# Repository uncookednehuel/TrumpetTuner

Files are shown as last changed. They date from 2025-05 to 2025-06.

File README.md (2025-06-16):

# TrumpetTuner
Resources of the capstone engineering project by Nehuel Armenanzas, Dylan Hong, and Logan Bruno

## Files
We currently have the final report PDF, the CAD models, the arduino source code, and some photos, all provided above. Let me know at coolnehuel@gmail.com if you have any questions or would like to know anything else about this project!

## Team
We are 3 seniors from Portsmouth High School, and we made this device prototype as our senior engineering capstone project. We all completed the Engineering CTE pathway, and are now graduated!

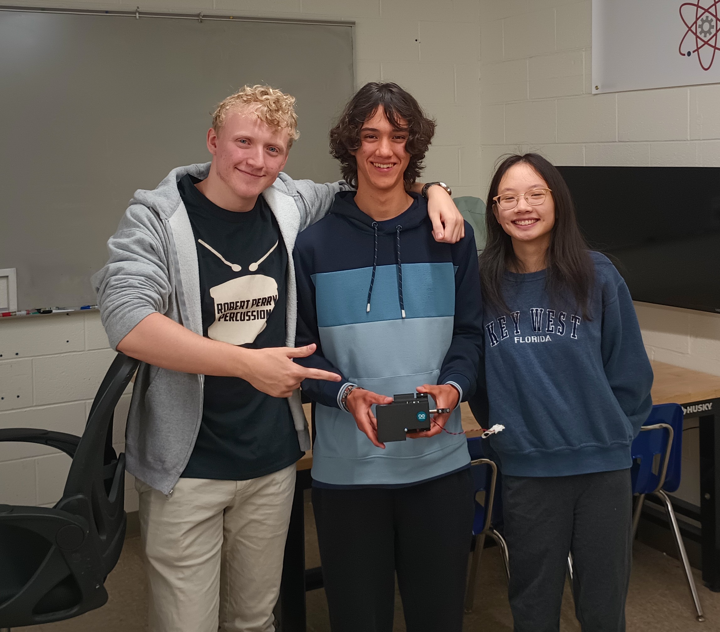
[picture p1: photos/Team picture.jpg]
Team picture with the final prototype! From left to right: Logan Bruno, Nehuel Armenanzas, Dylan Hong


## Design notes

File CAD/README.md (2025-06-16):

# CAD Files

[InventorDesigns](InventorDesigns) Contains the designs we made when we initially began with Autodesk Inventor. The only design in here that we used for the final prototype is the [Slide clip](InventorDesigns/SlideClip.ipt)

[FusionDesigns](FusionDesigns) Contains the designs we created after we switched to Autodesk Fusion 360. The [CaseAssembly](FusionDesigns/CaseAssembly%20v1.f3z) is our assembly file, which we only used to check interference.

[Case5](FusionDesigns/Case5%20v8.f3z) is our old case design, which we used for the first complete assembly and for prototyping, and [Case6](FusionDesigns/Case6%20v3.f3z) is our final case design, which adds geometry allowing for interface with the charger, switch, controls, and thus proper installment of the lid.

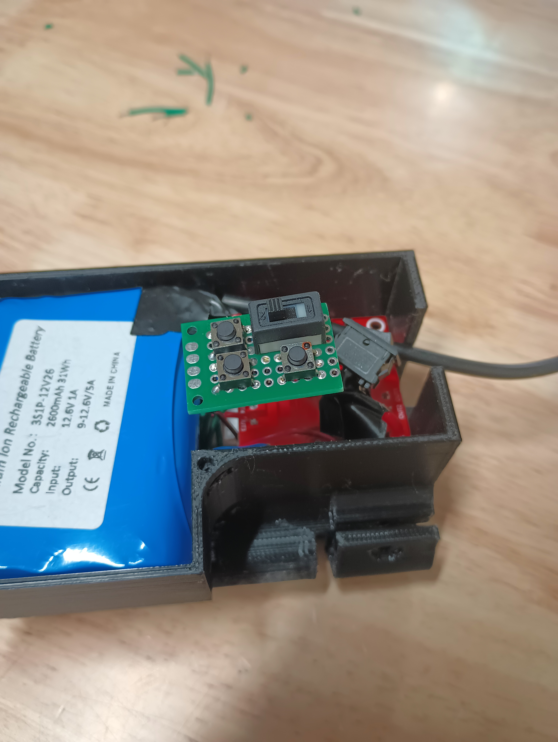
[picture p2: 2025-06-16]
photos/Closeup of controls.jpg

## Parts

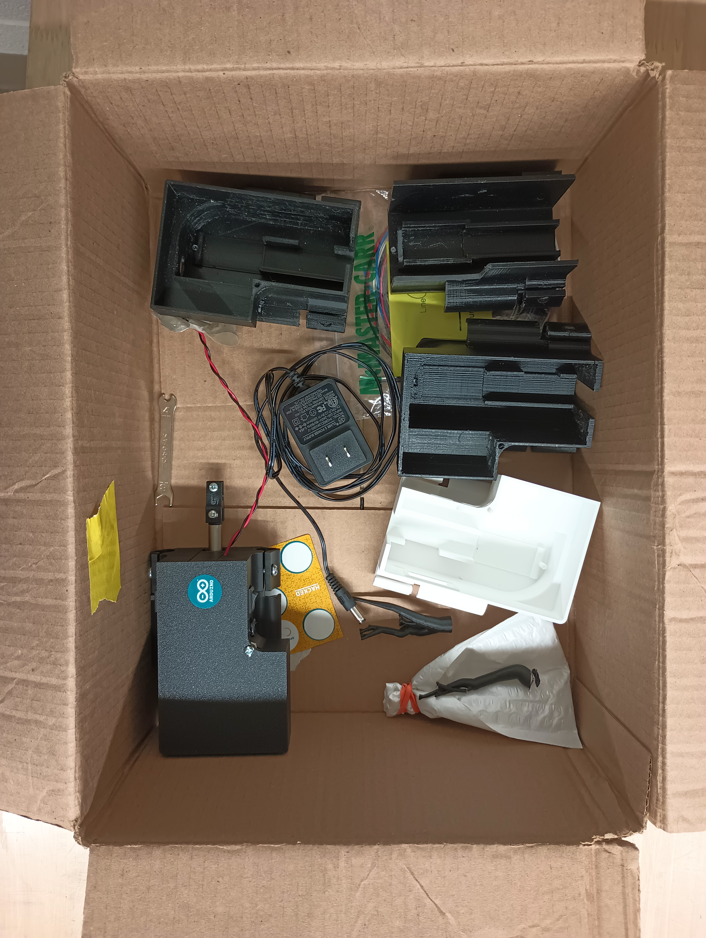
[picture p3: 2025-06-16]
photos/The final box of components we are keeping.jpg

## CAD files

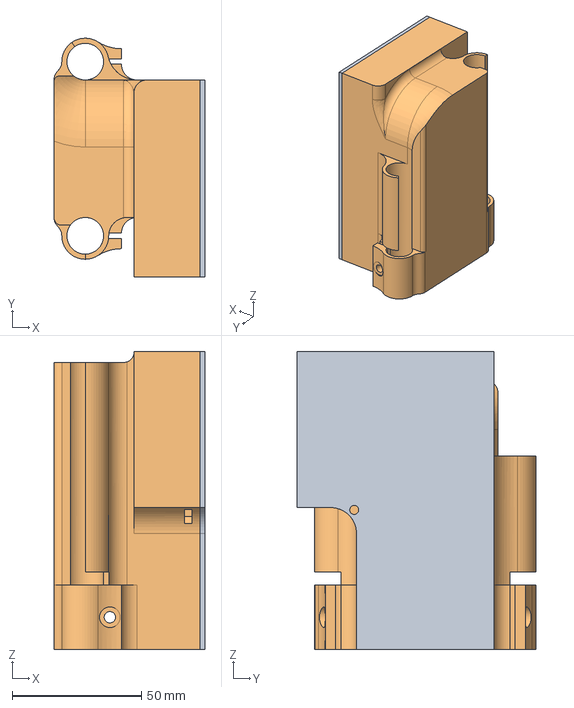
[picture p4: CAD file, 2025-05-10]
CAD/FusionDesigns/CaseAssembly v1.step
58.5 x 92.5 x 115.5 mm
Lid
Configuration 1

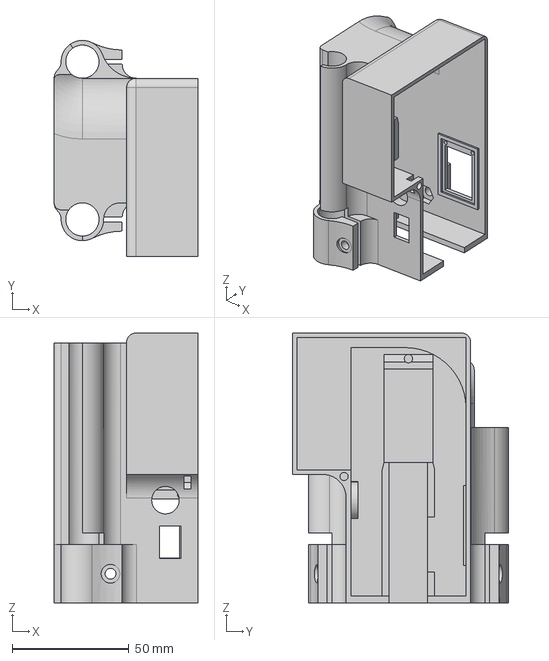
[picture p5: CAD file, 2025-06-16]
CAD/FusionDesigns/Case6 v3.step
61.5 x 92.5 x 115.5 mm

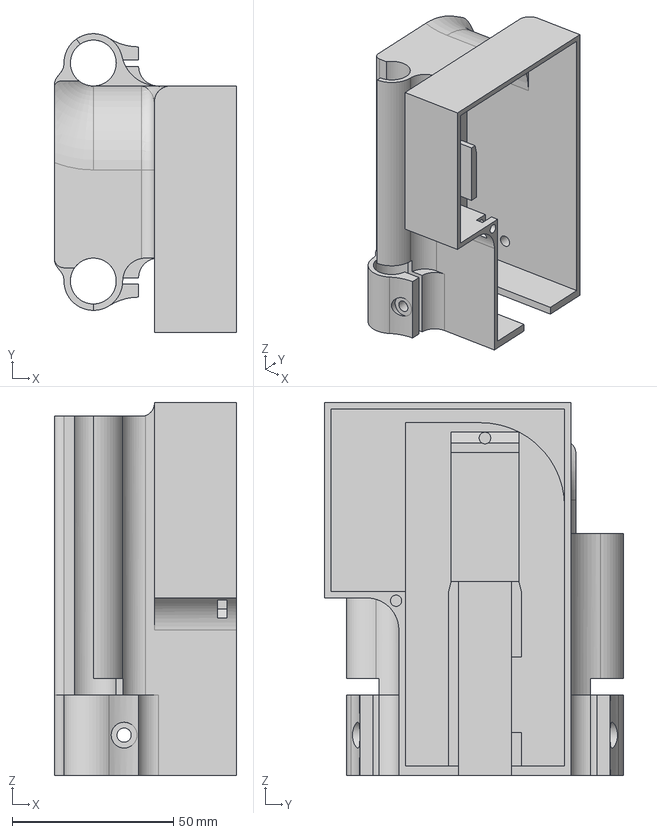
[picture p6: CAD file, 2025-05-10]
CAD/FusionDesigns/Case5 v8.step
56.5 x 92.5 x 115.5 mm

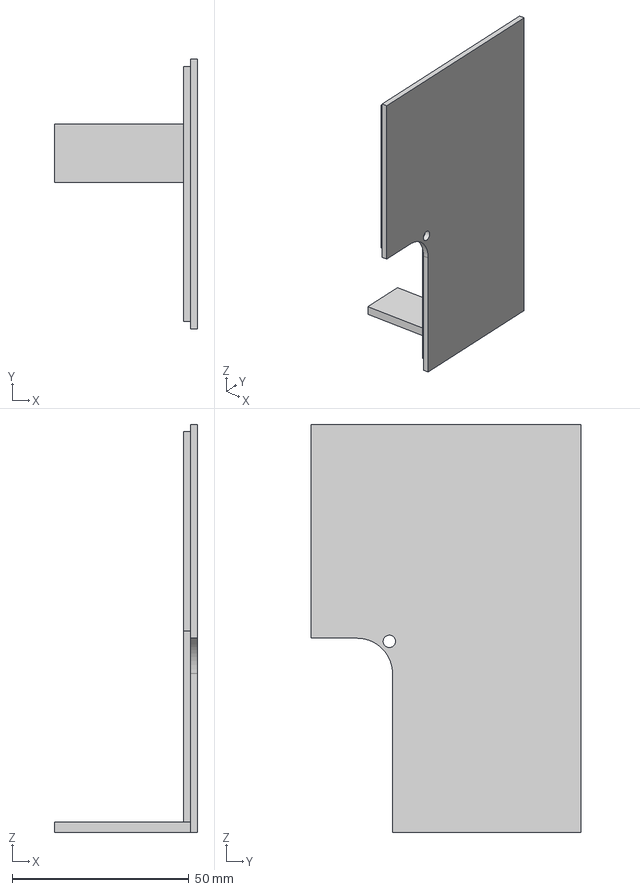
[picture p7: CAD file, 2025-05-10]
CAD/FusionDesigns/Lid v4.step
40.5 x 76.3 x 115.5 mm

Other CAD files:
CAD/FusionDesigns/Case5 v8.f3z
CAD/FusionDesigns/Case6 v3.f3d
CAD/FusionDesigns/Case6 v3.f3z
CAD/FusionDesigns/CaseAssembly v1.f3z
CAD/FusionDesigns/Lid v4.f3d
CAD/InventorDesigns/Assembly.iam
CAD/InventorDesigns/Casing.ipt
CAD/InventorDesigns/Slide.ipt
CAD/InventorDesigns/SlideClip.ipt
CAD/InventorDesigns/Trumpet.ipt

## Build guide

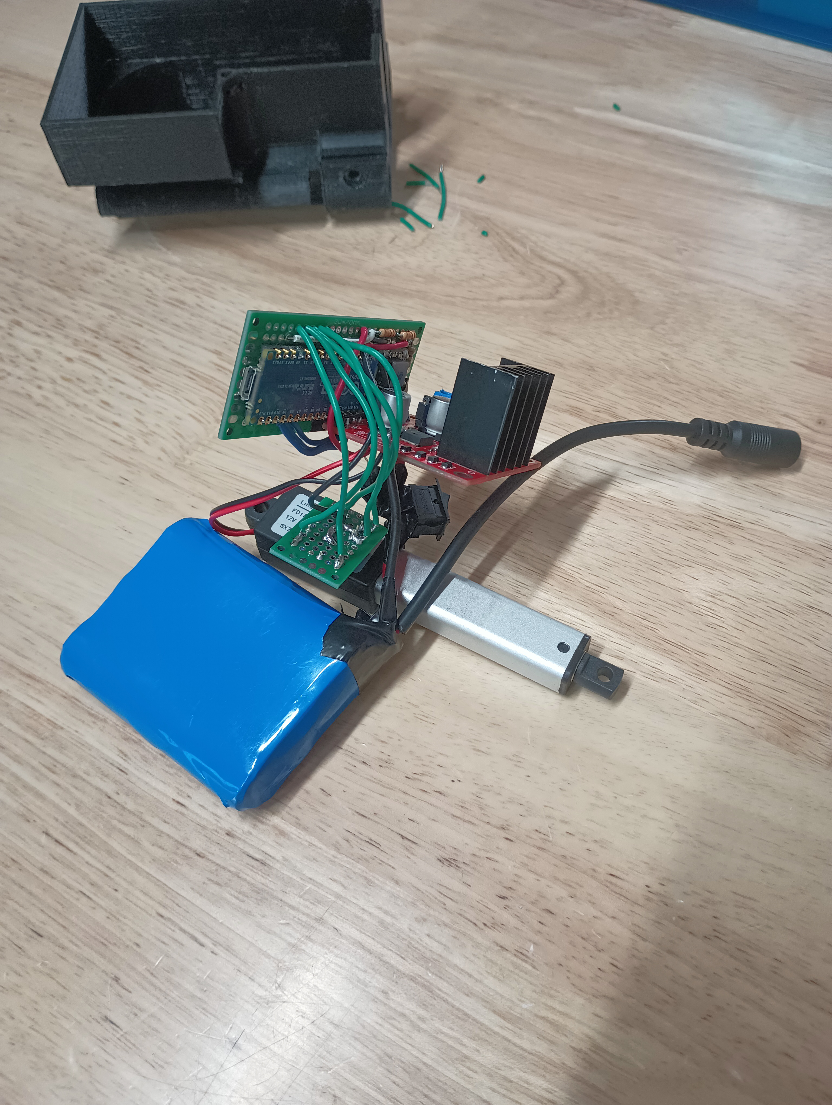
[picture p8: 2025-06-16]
photos/First complete wiring.jpg

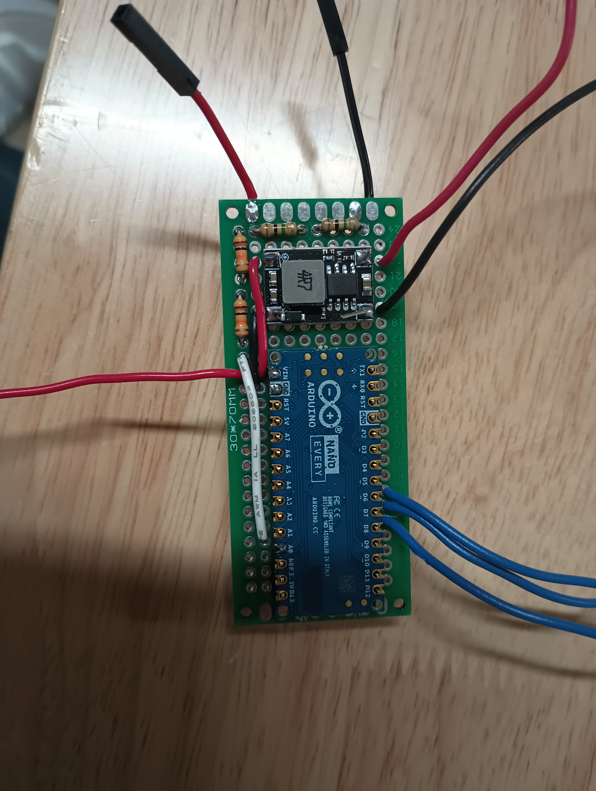
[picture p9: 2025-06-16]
photos/First protoboard wiring.jpg

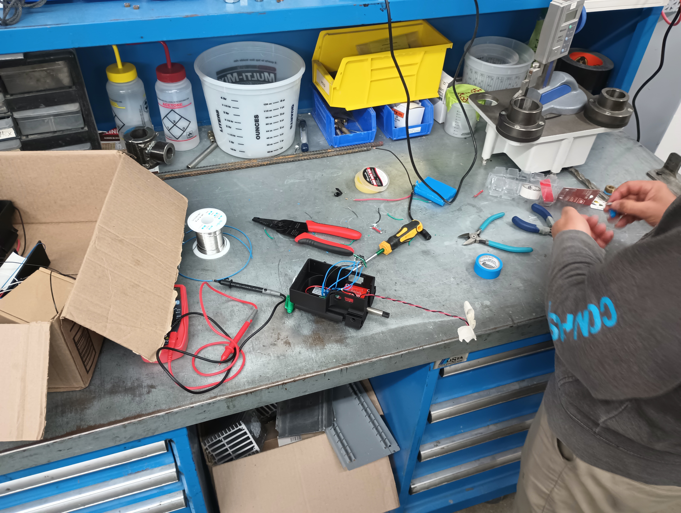
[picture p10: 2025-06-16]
photos/Rewiring the electronics for final assembly.jpg

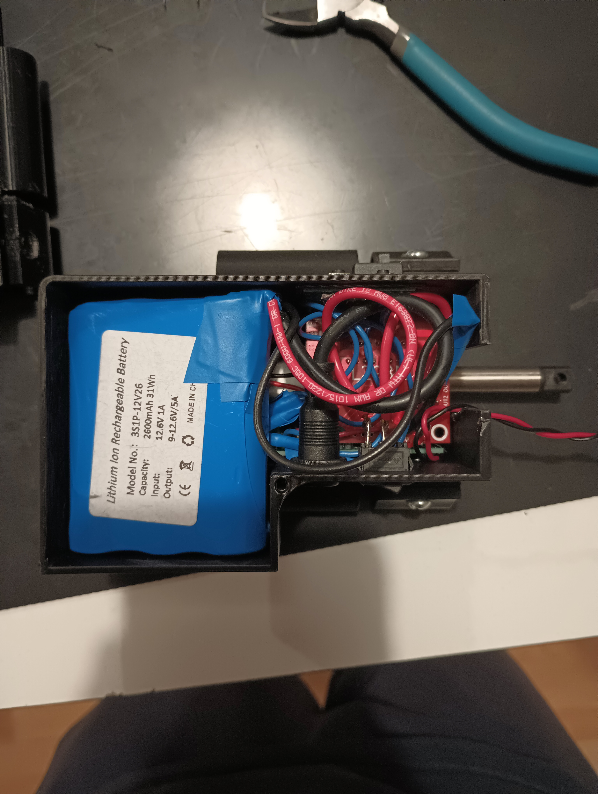
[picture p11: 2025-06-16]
photos/Final electronics assembly in new case.jpg

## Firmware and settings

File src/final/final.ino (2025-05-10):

#include "arduinoFFT.h"

#define CHANNEL A0

// Parameters
const float lowFrequency = 210;
const float highFrequency = 235;
const float magnitudeThreshold = 15;

const uint16_t samples = 512; // This value MUST ALWAYS be a power of 2
const float samplingFrequency = highFrequency * 2; // Hz
unsigned int sampling_period_us;
unsigned long microseconds;

// Math optimization
const float logTwo = log(2);

// Motor pins
const int pwmPin = 6;
const int dir1Pin = 7;
const int dir2Pin = 8;

const int enableContinuousPin = 12;
const int enableDiscretePin = 11;
const int tunePin = 5;
const int manualUpPin = 10;
const int manualDownPin = 9;

float vReal[samples];
float vImag[samples];

/* Create FFT object with weighing factor storage */

ArduinoFFT<float> FFT = ArduinoFFT<float>(vReal, vImag, samples, samplingFrequency, true);

#define SCL_INDEX 0x00
#define SCL_TIME 0x01
#define SCL_FREQUENCY 0x02
#define SCL_PLOT 0x03

void setup() {
  sampling_period_us = round(1000000*(1.0/samplingFrequency));

  //start serial connection
  Serial.begin(9600);

  // Button inputs
  pinMode(enableContinuousPin, INPUT_PULLUP);
  pinMode(enableDiscretePin, INPUT_PULLUP);
  pinMode(manualUpPin, INPUT_PULLUP);
  pinMode(manualDownPin, INPUT_PULLUP);
  pinMode(tunePin, INPUT_PULLUP);

  // Motor pins
  pinMode(pwmPin, OUTPUT); // PWM pin
  pinMode(dir1Pin, OUTPUT); // Dir 1
  pinMode(dir2Pin, OUTPUT); // Dir 2

  analogWrite(pwmPin, 255);
}

void loop() {
  // Read button inputs
  int enableContinuous = 1 - digitalRead(enableContinuousPin);
  String enableContinuousRead = "enableContinuous(" + String(enableContinuous) + ")";
  int enableDiscrete = 1 - digitalRead(enableDiscretePin);
  int tune = 1 - digitalRead(tunePin);
  int manualUp = 1 - digitalRead(manualUpPin);
  int manualDown = 1 - digitalRead(manualDownPin);

  // Manual up/down buttons
  if (manualUp ^ manualDown == 1) {
    digitalWrite(dir1Pin, manualUp == 1 ? HIGH : LOW);
    digitalWrite(dir2Pin, manualDown == 1 ? HIGH : LOW);
    Serial.println("Setting motor dir to high: " + String(manualUp == 1 ? HIGH : LOW) + " low: " + String(manualDown == 1 ? HIGH : LOW));\
    return;
  }

  // Return if in discrete mode and not tuning
  if(enableDiscrete == 1 && tune == 0) { 
    setDir(0);
    return;
  }

  // Sampling
  microseconds = micros();
  for(int i=0; i<samples; i++) {
      vReal[i] = analogRead(A0);
      vImag[i] = 0;
      while(micros() - microseconds < sampling_period_us) { /* Empty loop*/ }
      microseconds += sampling_period_us;
  }

  FFT.windowing(FFTWindow::Hamming, FFTDirection::Forward);	// Weigh data
  FFT.compute(FFTDirection::Forward); // Compute FFT
  FFT.complexToMagnitude(); // Compute magnitudes
  float x = findFundemental(vReal, (samples >> 1));

  // Auto tuning
  float dir = calculateCents(x);
  Serial.println(String(x) + " : " + String(dir));

  float absoluteDir = dir > 0 ? dir : -dir;
  if ((absoluteDir > 0.10) && x != 0) {
    setDir((dir * -1) / absoluteDir);
    delay(500);
    setDir(0);
  } else {
    setDir(0);
  }
}

void setDir(int dir) {
  if (dir == -1) {
    digitalWrite(dir1Pin, LOW);
    digitalWrite(dir2Pin, HIGH);
    return;
  }
  if (dir == 1) {
    digitalWrite(dir1Pin, HIGH);
    digitalWrite(dir2Pin, LOW);
    return;
  }
  if (dir == 0) {
    digitalWrite(dir1Pin, LOW);
    digitalWrite(dir2Pin, LOW);
    return;
  }
}

// n = 12 * log₂(f/440 Hz)
float calculateCents(float frequency) {
  float fromA4 = 12 * (log(frequency / 440) / logTwo);
  return fromA4 - round(fromA4);
}

// Finds the fundamental frequency by looping through samples and finding the peak that fits through the filter
float findFundemental(float *vData, uint16_t bufferSize) {
  // Pre-calculates the index range to reduce loop iterations
  int firstIndex = frequencyIndex(lowFrequency);
  int lastIndex = frequencyIndex(highFrequency);
  float bestFrequency = 0;
  float bestMagnitude = 0;

  for (uint16_t i = firstIndex; i < lastIndex; i++) {
    // Calculates frequency currently being tested
    float frequency = ((i * 1.0 * samplingFrequency) / samples);
    float magnitude = vData[i];

    //Filters out based on magnitude and frequency
    if (magnitude > bestMagnitude && magnitude > magnitudeThreshold && frequency > lowFrequency && frequency < highFrequency) {
      bestMagnitude = magnitude;
      bestFrequency = frequency;
    }
  }
  return bestFrequency;
}

float frequencyIndex(float frequency) {
  return (frequency * samples) / samplingFrequency;
}

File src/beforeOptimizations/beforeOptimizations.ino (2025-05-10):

#include "arduinoFFT.h"

#define CHANNEL A0
const uint16_t samples = 512; //This value MUST ALWAYS be a power of 2
const float samplingFrequency = 1000; //Hz
unsigned int sampling_period_us;
unsigned long microseconds;

int pwmPin = 6;
int dir1 = 7;
int dir2 = 8;

float vReal[samples];
float vImag[samples];

/* Create FFT object with weighing factor storage */

ArduinoFFT<float> FFT = ArduinoFFT<float>(vReal, vImag, samples, samplingFrequency, true);

#define SCL_INDEX 0x00
#define SCL_TIME 0x01
#define SCL_FREQUENCY 0x02
#define SCL_PLOT 0x03

void setup() {
  sampling_period_us = round(1000000*(1.0/samplingFrequency));

  //start serial connection
  Serial.begin(9600);

  // Button inputs
  pinMode(12, INPUT_PULLUP);
  pinMode(11, INPUT_PULLUP);
  pinMode(10, INPUT_PULLUP);
  pinMode(9, INPUT_PULLUP);
  pinMode(5, INPUT_PULLUP);

  // Motor pins
  pinMode(pwmPin, OUTPUT); // PWM pin
  pinMode(dir1, OUTPUT); // Dir 1
  pinMode(dir2, OUTPUT); // Dir 2
}

void loop() {
  // Read button inputs
  int enableContinuous = 1 - digitalRead(12);
  String enableContinuousRead = "enableContinuous(" + String(enableContinuous) + ")";
  int enableDiscrete = 1 - digitalRead(11);
  int tune = 1 - digitalRead(5);
  int manualUp = 1 - digitalRead(10);
  int manualDown = 1 - digitalRead(9);

  // Sampling
  microseconds = micros();
  for(int i=0; i<samples; i++) {
      vReal[i] = analogRead(A0);
      vImag[i] = 0;
      while(micros() - microseconds < sampling_period_us) { /* Empty loop*/ }
      microseconds += sampling_period_us;
  }

  FFT.windowing(FFTWindow::Hamming, FFTDirection::Forward);	// Weigh data
  FFT.compute(FFTDirection::Forward); // Compute FFT
  FFT.complexToMagnitude(); // Compute magnitudes
  float x = findFundemental(vReal, (samples >> 1));

  // Set the direction of the motor by switching the H bridge using the two direction pins
  if (manualUp ^ manualDown == 1) {
    digitalWrite(dir1, manualUp == 1 ? HIGH : LOW);
    digitalWrite(dir2, manualDown == 1 ? HIGH : LOW);
    Serial.println("Setting motor dir to high: " + String(manualUp == 1 ? HIGH : LOW) + " low: " + String(manualDown == 1 ? HIGH : LOW));
  } else {
    // Auto tuning
    float dir = calculateDirection(x);
    Serial.println(x);
    //Serial.println(dir);
    float absoluteDir = dir > 0 ? dir : -dir;
    if ((x > 150) && (absoluteDir > 0.15) && !isnan(x)) {
      int range = 200;
      //int power = constrain((255 - range) + round(range * absoluteDir), 0, 255);
      int power = 255;
      Serial.println("amonmg");
      analogWrite(pwmPin, power);
      if (dir > 0) {
        digitalWrite(dir1, LOW);
        digitalWrite(dir2, HIGH);
      } else {
        digitalWrite(dir1, HIGH);
        digitalWrite(dir2, LOW);
      }
    } else {
      // Set motor power to half (0 to 255)
      analogWrite(pwmPin, 255);
      digitalWrite(dir1, LOW);
      digitalWrite(dir2, LOW);
    }
  }
}

// n = 12 * log₂(f/440 Hz)
float calculateDirection(float frequency) {
  float fromA4 = 12 * (log(frequency / 440) / log(2));
  return fromA4 - round(fromA4);
}

float findFundemental(float *vData, uint16_t bufferSize) {
  float bestFrequency = 0;
  float bestMagnitude = 0;
  for (uint16_t i = 0; i < bufferSize; i++) {
    float frequency = ((i * 1.0 * samplingFrequency) / samples); // Frequency it is at
    float magnitude = vData[i];

    if (magnitude > bestMagnitude && magnitude > 50 && frequency > 200 && frequency < 250) {
      bestMagnitude = magnitude;
      bestFrequency = frequency;
    }
  }
  return bestFrequency;
}

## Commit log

2025-05-10 CAD files, arduino code
    [Assembly.iam, Case5 v8.f3z, Case5 v8.step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]
2025-06-16 Uploaded final case CAD, organised a bit
    [Assembly.iam, Case6 v3.f3d, Case6 v3.f3z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]
2025-06-16 Update cad README.md
2025-06-16 Fixed CAD README links
